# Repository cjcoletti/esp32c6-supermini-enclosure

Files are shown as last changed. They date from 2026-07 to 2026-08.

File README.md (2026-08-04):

# Enclosure — ESP32-C6 Super Mini + mini fonte





Caixa compacta para o Matter switch (ESP32-C6 Super Mini + mini fonte Hilink).

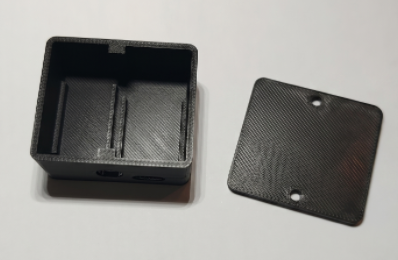
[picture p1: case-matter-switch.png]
Caixa 3D impressa — base e tampa


> Modelo paramétrico **V16.4** — placas dispostas lado a lado, trilhos de encaixe por pressão, furo Ø8 centralizado no vão e furo para a USB-C para deploy/debug da ESP32 via JTAG.

## Sobre este projeto

**ESP32-C6 Super Mini Enclosure** é um projeto **pessoal e de código aberto**, criado como **contribuição à comunidade** de desenvolvedores Matter/ESP32.

- Funciona em ambiente de laboratório e pode ser **reutilizado, estudado e adaptado** livremente.
- **Não é um produto comercial** — não há suporte oficial, garantia ou certificação de segurança elétrica.
- Compatível com o firmware [Magic Button (esp32-sw-matter-ota)](https://github.com/cjcoletti/esp32-sw-matter-ota), mas pode ser usado com outras montagens similares.

**Status:** release **v1.0.0** (modelo paramétrico **V16.4**) testado em impressão 3D (PLA/PETG) com ESP32-C6 Super Mini e mini fonte Hilink.

| Campo | Valor |
| ----- | ----- |
| Release | `v1.0.0` |
| Modelo paramétrico (OpenSCAD) | `V16.4` |

## Estrutura

```text
esp32c6-supermini-enclosure/
├── README.md
├── README.en.md
├── CONTRIBUTING.md
├── CONTRIBUTING.en.md
├── SECURITY.md
├── LICENSE
├── .github/             # templates de Issues e release notes
├── case.scad
├── base.stl
├── tampa.stl
└── case-matter-switch.png
```

## Arquivos

| Arquivo | Uso |
|---|-----|
| `base.stl` | Caixa base (imprimir) |
| `tampa.stl` | Tampa (imprimir) |
| `case.scad` | Fonte paramétrica (OpenSCAD) |
| `case-matter-switch.png` | Foto da caixa impressa (base + tampa) |

## Dimensões externas

| Eixo | mm |
|---|-----|
| Largura (X, fonte \|\| ESP) | **45,0** |
| Profundidade (Y, eixos longos das placas) | **38,3** |
| Altura montada | **24,5** (base 22,5 + tampa 2,0) |

Paredes **2 mm**; cantos externos arredondados (**r = 3 mm**).

## Componentes

| Módulo | Dimensões (mm) | Orientação |
|---|---|---|
| Fonte | 20 × 34 × (15 + 5) (largura × profundidade × altura (fonte + pinos)) | Deitada |
| ESP32-C6 | 18 × 26 × 20 (largura × profundidade × altura) | Em pé |

Folga de encaixe no CAD: **0,3 mm** (`folga_encaixe`).

## Layout interno

Vista superior (tampa removida):

```
  Y=38 (traseira)
  +--------+----+--------+
  |        |boss|        |
  |  FONTE | 2mm|  ESP   |
  | trilho |vão | trilho |
  |  18 mm |    |  21 mm |
  |        |boss|        |
  +--------+-Ø8-+--USB-C-+
  Y=0 (frente)
```

- **Fonte (esquerda):** trilhos laterais com vão interno de **15 mm**; guia por pressão até o fundo (altura do guia **4 mm**).
- **ESP (direita):** trilhos com vão interno de **18 mm**; profundidade total da placa (**26,3 mm** com folga); **batente traseiro** entre os trilhos (**1,5 × 6 mm**, espessura × altura) para impedir a placa de escorregar para o vão atrás.
- **Vão central:** **2 mm** entre os trilhos (pinos / headers).
- **Trilhos:** abas de **1,5 mm** de cada lado; a placa desliza entre elas até assentar no fundo.

## Aberturas na face frontal (Y = 0)

| Abertura | Especificação |
|---|---|
| USB-C | Perfil stadium **10,0 × 4,5 mm** (horizontal), alinhado à ESP |
| Fios | **Ø 8 mm**, centralizado no vão (X = centro do vão), logo abaixo do boss frontal |

## Fixação

Tampa com 2 furos de parafusos de **2× M2 × 6 mm**, centralizados na largura (eixo do vão):

- Bosses na parede **frontal** e **traseira** (altura **7,5 mm**).
- Piloto cego **Ø 2,0 mm**, profundidade **6 mm** na caixa.
- Furo passante **Ø 2,4 mm** na tampa, com rebaixo de cabeça (**Ø 4,2 mm**).

## Impressão sugerida

- PLA ou PETG, camada **0,2 mm**, **2–3 perímetros**, 15–20% infill
- Sem suporte: base com fundo no leito; tampa plana no leito
- Testar encaixe dos trilhos e do USB-C antes de fechar a caixa

## Editar online

Para visualizar ou ajustar o modelo sem instalar o OpenSCAD, abra `case.scad` em [PrintPal CAD Agent](https://printpal.io/cad-agent).

## Regenerar STLs

Abra `case.scad` no OpenSCAD:

1. `visualizar_tampa = false` → renderizar e exportar **base**
2. `visualizar_tampa = true` → renderizar e exportar **tampa**

**File → Export → Export as STL** (`base.stl` / `tampa.stl`).

## Contribuições

Este projeto é mantido de forma pessoal. **Sugestões e ideias são bem-vindas** via [Issues](https://github.com/cjcoletti/esp32c6-supermini-enclosure/issues/new/choose)
(ou Discussions). Por favor, **não envie Pull Requests** — prefiro implementar mudanças
eu mesmo, no meu ritmo. Você pode fazer fork para uso **não comercial** (hobby, estudo, lab), conforme a licença PolyForm Noncommercial.

Detalhes em [CONTRIBUTING.md](CONTRIBUTING.md).

## Segurança

Para reportar vulnerabilidades em privado, veja [SECURITY.md](SECURITY.md) (em inglês).

## Licença

Licenciado sob a [PolyForm Noncommercial License 1.0.0](LICENSE). Aplica-se a **todo o repositório**, incluindo release `v1.0.0` e versões futuras (relicenciado de MIT em agosto/2026).

Uso permitido para fins **não comerciais** (hobby, estudo, laboratório, organizações sem fins lucrativos). Uso comercial (venda de produto, serviço pago etc.) **não** é permitido sem autorização do autor.

## Aviso legal

Este software é fornecido **"como está"**, sem garantias de qualquer tipo. O autor não se responsabiliza por danos decorrentes do uso. Matter® é marca da Connectivity Standards Alliance; este projeto não é afiliado à CSA nem à Espressif.

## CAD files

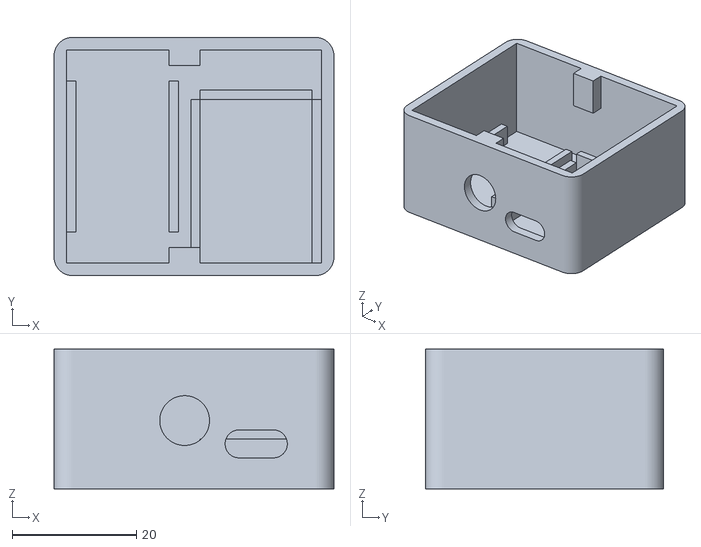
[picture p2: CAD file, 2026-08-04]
base.stl
45.0 x 38.3 x 22.5

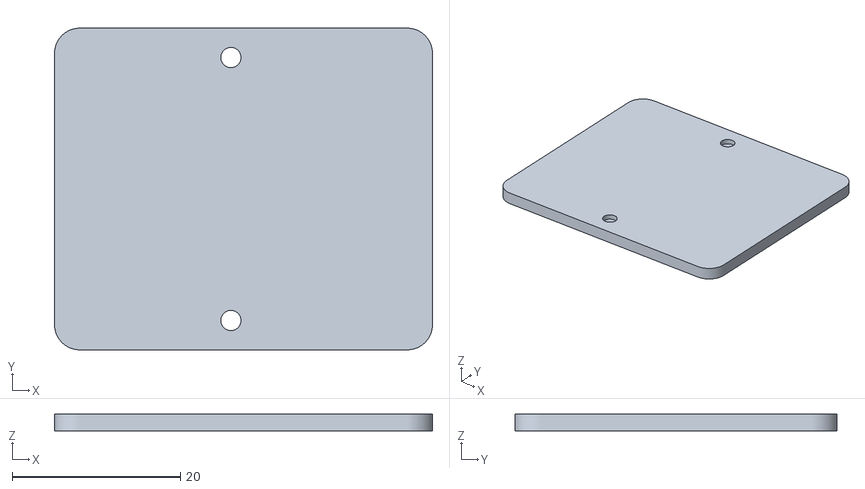
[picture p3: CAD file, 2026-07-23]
tampa.stl
45.0 x 38.3 x 2.00

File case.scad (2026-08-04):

// =======================================================
// ENCLOSURE ULTRA-COMPACTA V16.4 - FURO 8MM CENTRALIZADO OK
// =======================================================

$fn = 64; // Alta resolução para furos e encaixes

// --- PARÂMETROS DA CAIXA ---
espessura_parede = 2.0;
folga_encaixe = 0.3; // Tolerância para encaixe suave
vao_central = 2.0; // Distância entre as duas placas em pé
raio_canto = 3.0; // Raio de arredondamento dos cantos externos

// --- ESPAÇOS INTERNOS DOS TRILHOS (GUIA POR PRESSÃO) ---
espaco_trilho_fonte = 15.0; // Espaço exato interno livre entre os trilhos da fonte
espaco_trilho_esp = 18.0;   // Espaço exato interno livre entre os trilhos da ESP32

// --- DIMENSÕES DAS PLACAS ---
fonte_altura = 20.0 + folga_encaixe; // Altura em pé: 20.3 mm
esp_altura = 18.0 + folga_encaixe;   // Altura em pé: 18.3 mm

fonte_profundo = 34.0 + folga_encaixe; // 34.3 mm
esp_profundo = 26.0 + folga_encaixe;  // 26.3 mm

// --- CÁLCULO DE LARGURA DOS TRILHOS NA BASE ---
aba_trilho = 1.5; // Espessura da parede do trilho
largura_total_trilho_fonte = espaco_trilho_fonte + (aba_trilho * 2); // 18.0 mm
largura_total_trilho_esp = espaco_trilho_esp + (aba_trilho * 2);     // 21.0 mm

// --- DIMENSÕES INTERNAS TOTAIS ---
interno_L = largura_total_trilho_fonte + vao_central + largura_total_trilho_esp; // ~41.0 mm
interno_P = max(fonte_profundo, esp_profundo); // 34.3 mm

// --- ALTURA AJUSTADA PARA COMPENSAR A TAMPA MACIÇA ---
interno_A = 20.5; 
externo_A = interno_A + espessura_parede; // 22.5 mm de altura externa da caixa base

// --- DIMENSÕES EXTERNAS TOTAIS ---
externo_L = interno_L + (espessura_parede * 2);
externo_P = interno_P + (espessura_parede * 2);

// --- COORDENADAS DE ANCORAGEM (Placas em Pé) ---
fonte_X = espessura_parede;
esp_X = externo_L - espessura_parede - largura_total_trilho_esp;

centro_vao_X = espessura_parede + largura_total_trilho_fonte + (vao_central / 2);

// --- CONFIGURAÇÃO DE PARAFUSOS M2 ---
m2_diametro = 2.0;
m2_profundidade = 6.0;
boss_diametro = 5.0; 
boss_altura_frontal = m2_profundidade + 1.5; // 7.5 mm

// =======================================================
// CONTROLE DE VISUALIZAÇÃO
// =======================================================
// Mude para 'false' para gerar a Caixa Base ou 'true' para gerar a Tampa
visualizar_tampa = false; 

if (visualizar_tampa) {
    tampa();
} else {
    caixa_base();
}

// =======================================================
// MÓDULOS AUXILIARES
// =======================================================

// Gera um cubo com cantos arredondados no plano X-Y
module cubo_arredondado(l, p, a, r) {
    translate([r, r, 0])
    minkowski() {
        cube([l - 2*r, p - 2*r, a - 0.1]);
        cylinder(r=r, h=0.1);
    }
}

// Gera trilhos guia laterais onde a placa desliza pelo meio até tocar o fundo
module trilhos_guia_lateral(espaco_interno, profundidade, altura_guia) {
    // Guia Esquerda
    cube([aba_trilho, profundidade, altura_guia]);
    // Guia Direita
    translate([aba_trilho + espaco_interno, 0, 0])
    cube([aba_trilho, profundidade, altura_guia]);
}

// =======================================================
// MÓDULOS DO PROJETO
// =======================================================

module caixa_base() {
    difference() {
        // 1. Corpo Externo Maciço ARREDONDADO
        cubo_arredondado(externo_L, externo_P, externo_A, raio_canto);
        
        // 2. Cavidade Interna Principal (Totalmente desimpedida até o fundo)
        translate([espessura_parede, espessura_parede, espessura_parede])
        cube([interno_L, interno_P, interno_A + 1]);
        
        // 3. Furo USB-C Realístico Arredondado (Horizontal)
        usb_L_folga = 10.0;
        usb_A_folga = 4.5;
        
        pos_usb_x = esp_X + (largura_total_trilho_esp / 2);
        pos_usb_z_centro = espessura_parede + 3.0 + (usb_A_folga / 2); 
        
        translate([pos_usb_x, -1, pos_usb_z_centro])
        rotate([-90, 0, 0]) 
        furo_usbc_perfil(usb_L_folga, usb_A_folga, espessura_parede + 2);
        
        // 4. Furo Frontal de 8mm para Passagem de Fios
        // AJUSTADO: Posicionado para ficar o mais alto possível, iniciando imediatamente abaixo do boss
        pos_furo_8mm_z = (externo_A - boss_altura_frontal) - 4.0; // 11.0 mm (centro perfeito)
        translate([centro_vao_X, -1, pos_furo_8mm_z])
        rotate([-90, 0, 0])
        cylinder(d=8, h=espessura_parede + 3);
        
        // 5. Furos Guia M2 dentro dos Bosses (Cego com 6mm de profundidade)
        translate([centro_vao_X, espessura_parede + (boss_diametro/2) - 1, externo_A - m2_profundidade])
        cylinder(d=m2_diametro, h=m2_profundidade + 1);
        
        translate([centro_vao_X, externo_P - espessura_parede - (boss_diametro/2) + 1, externo_A - m2_profundidade])
        cylinder(d=m2_diametro, h=m2_profundidade + 1);
    }
 
    // 6. Bosses Suspensos para os parafusos M2
    translate([centro_vao_X - (boss_diametro/2), espessura_parede, externo_A - boss_altura_frontal])
    cube([boss_diametro, boss_diametro/2, boss_altura_frontal]);
    
    translate([centro_vao_X - (boss_diametro/2), externo_P - espessura_parede - (boss_diametro/2), externo_A - boss_altura_frontal])
    cube([boss_diametro, boss_diametro/2, boss_altura_frontal]);
    
    // 7. Trilhos Guia de Encaixe por Pressão
    // TRILHO DA FONTE: Reduzido 5mm na frente e 5mm atrás (comprimento = fonte_profundo - 10)
    pos_fonte_Y = espessura_parede + (interno_P - fonte_profundo) + 5.0;
    comp_trilho_fonte = fonte_profundo - 10.0;
    translate([fonte_X, pos_fonte_Y, espessura_parede]) 
        trilhos_guia_lateral(espaco_trilho_fonte, comp_trilho_fonte, 4.0);
        
    // TRILHO DA ESP32: Mantido na profundidade total de sua placa
    translate([esp_X, espessura_parede, espessura_parede]) 
        trilhos_guia_lateral(espaco_trilho_esp, esp_profundo, 4.0);

    // Batente traseiro da ESP: impede a placa de escorregar para o vão atrás
    batente_esp_espessura = 1.5;
    batente_esp_altura = 6.0;
    translate([
        esp_X + aba_trilho,
        espessura_parede + esp_profundo,
        espessura_parede
    ])
    cube([espaco_trilho_esp, batente_esp_espessura, batente_esp_altura]);
}

module furo_usbc_perfil(largura, altura, profundidade) {
    raio = altura / 2;
    distancia_centros = largura - altura;
    hull() {
        translate([-distancia_centros/2, 0, 0])
        cylinder(r=raio, h=profundidade);
        translate([distancia_centros/2, 0, 0])
        cylinder(r=raio, h=profundidade);
    }
}

module tampa() {
    difference() {
        // Tampa simplificada: totalmente maciça por baixo (plana), com cantos arredondados
        cubo_arredondado(externo_L, externo_P, espessura_parede, raio_canto);
        
        // Furo Passante M2 Frontal na Tampa
        translate([centro_vao_X, espessura_parede + (boss_diametro/2) - 1, -1]) {
            cylinder(d=2.4, h=espessura_parede + 2);
            translate([0,0, espessura_parede - 1.2]) 
            cylinder(d1=2.4, d2=4.2, h=1.4); 
        }
 
        // Furo M2 Traseiro na Tampa
        translate([centro_vao_X, externo_P - espessura_parede - (boss_diametro/2) + 1, -1]) {
            cylinder(d=2.4, h=espessura_parede + 2);
            translate([0,0, espessura_parede - 1.2]) 
            cylinder(d1=2.4, d2=4.2, h=1.4); 
        }
    }
}

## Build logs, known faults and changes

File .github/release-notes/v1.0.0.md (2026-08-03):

# ESP32-C6 Super Mini Enclosure v1.0.0

First public release of the **3D-printable enclosure** for **ESP32-C6 Super Mini** + Hilink mini PSU — parametric model **V16.3**.

## Highlights

- Compact snap-fit case with side-by-side board layout
- Press-fit rails for PSU and ESP32-C6 Super Mini
- Front openings: **USB-C** (stadium profile) and **Ø 8 mm** wire pass-through
- Lid secured with **2× M2 × 6 mm** screws
- Bilingual documentation (Portuguese and English)

## External dimensions

| Axis | mm |
|---|-----|
| Width (X) | **45.0** |
| Depth (Y) | **38.3** |
| Assembled height | **24.5** (base 22.5 + lid 2.0) |

## Files in this release

| File | Purpose |
|---|---|
| `base.stl` | Case base (print) |
| `tampa.stl` | Lid (print) |
| `case.scad` | Parametric source (OpenSCAD) — model **V16.3** |
| `case-matter-switch.png` | Photo of printed case |

## Versioning

| Field | Value |
| ----- | ----- |
| Release | `v1.0.0` |
| Parametric model (OpenSCAD) | `V16.3` |

GitHub releases use **semver** (`v1.0.x`). The OpenSCAD model version (`V16.3`) tracks internal design iterations and is documented in release notes.

## Tested in development

- 3D printing in PLA and PETG
- Snap-fit rails for ESP32-C6 Super Mini and Hilink mini PSU
- USB-C opening alignment for deploy/debug
- Compatible with [Magic Button (esp32-sw-matter-ota)](https://github.com/cjcoletti/esp32-sw-matter-ota)

## Important notices

- **Not a commercial product** — no official support, warranty, or electrical safety certification
- Provided **"as is"** under the [PolyForm Noncommercial License 1.0.0](LICENSE)
- Suggestions welcome via [Issues](https://github.com/cjcoletti/esp32c6-supermini-enclosure/issues); Pull Requests are not accepted — see [CONTRIBUTING.en.md](CONTRIBUTING.en.md)

## Full changelog

Initial open-source release.

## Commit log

2026-07-23 Feat: Commit inicial do projeto
    [base.stl, case.scad, tampa.stl]
2026-08-03 feat: Add batente traseiro da ESP32
    [case.scad]
2026-08-03 feat: update base.stl
    [base.stl]
2026-08-03 docs: document ESP rear stop (6 mm) in READMEs
2026-08-04 feat: adjusting ESP32 pcb to 26 mm
    [case.scad]
2026-08-04 Updating base.stl
    [base.stl]

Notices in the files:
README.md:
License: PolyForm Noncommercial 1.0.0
